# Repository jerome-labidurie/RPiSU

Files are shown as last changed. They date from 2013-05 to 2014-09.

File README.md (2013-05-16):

INSTALL:

* Make your own PCB
* Burn firmware
* Connect wires (take a look in PCB files)
* Press On/Off button to start Raspberry Pi
* Copy RPiSU.sh to users home dir
* Execute 'sudo chmod 766 /home/users home dir/RPiSU.sh'
* Add command '/home/user/RPiSU.sh &' above 'exit 0' in /etc/rc.local
* Reboot

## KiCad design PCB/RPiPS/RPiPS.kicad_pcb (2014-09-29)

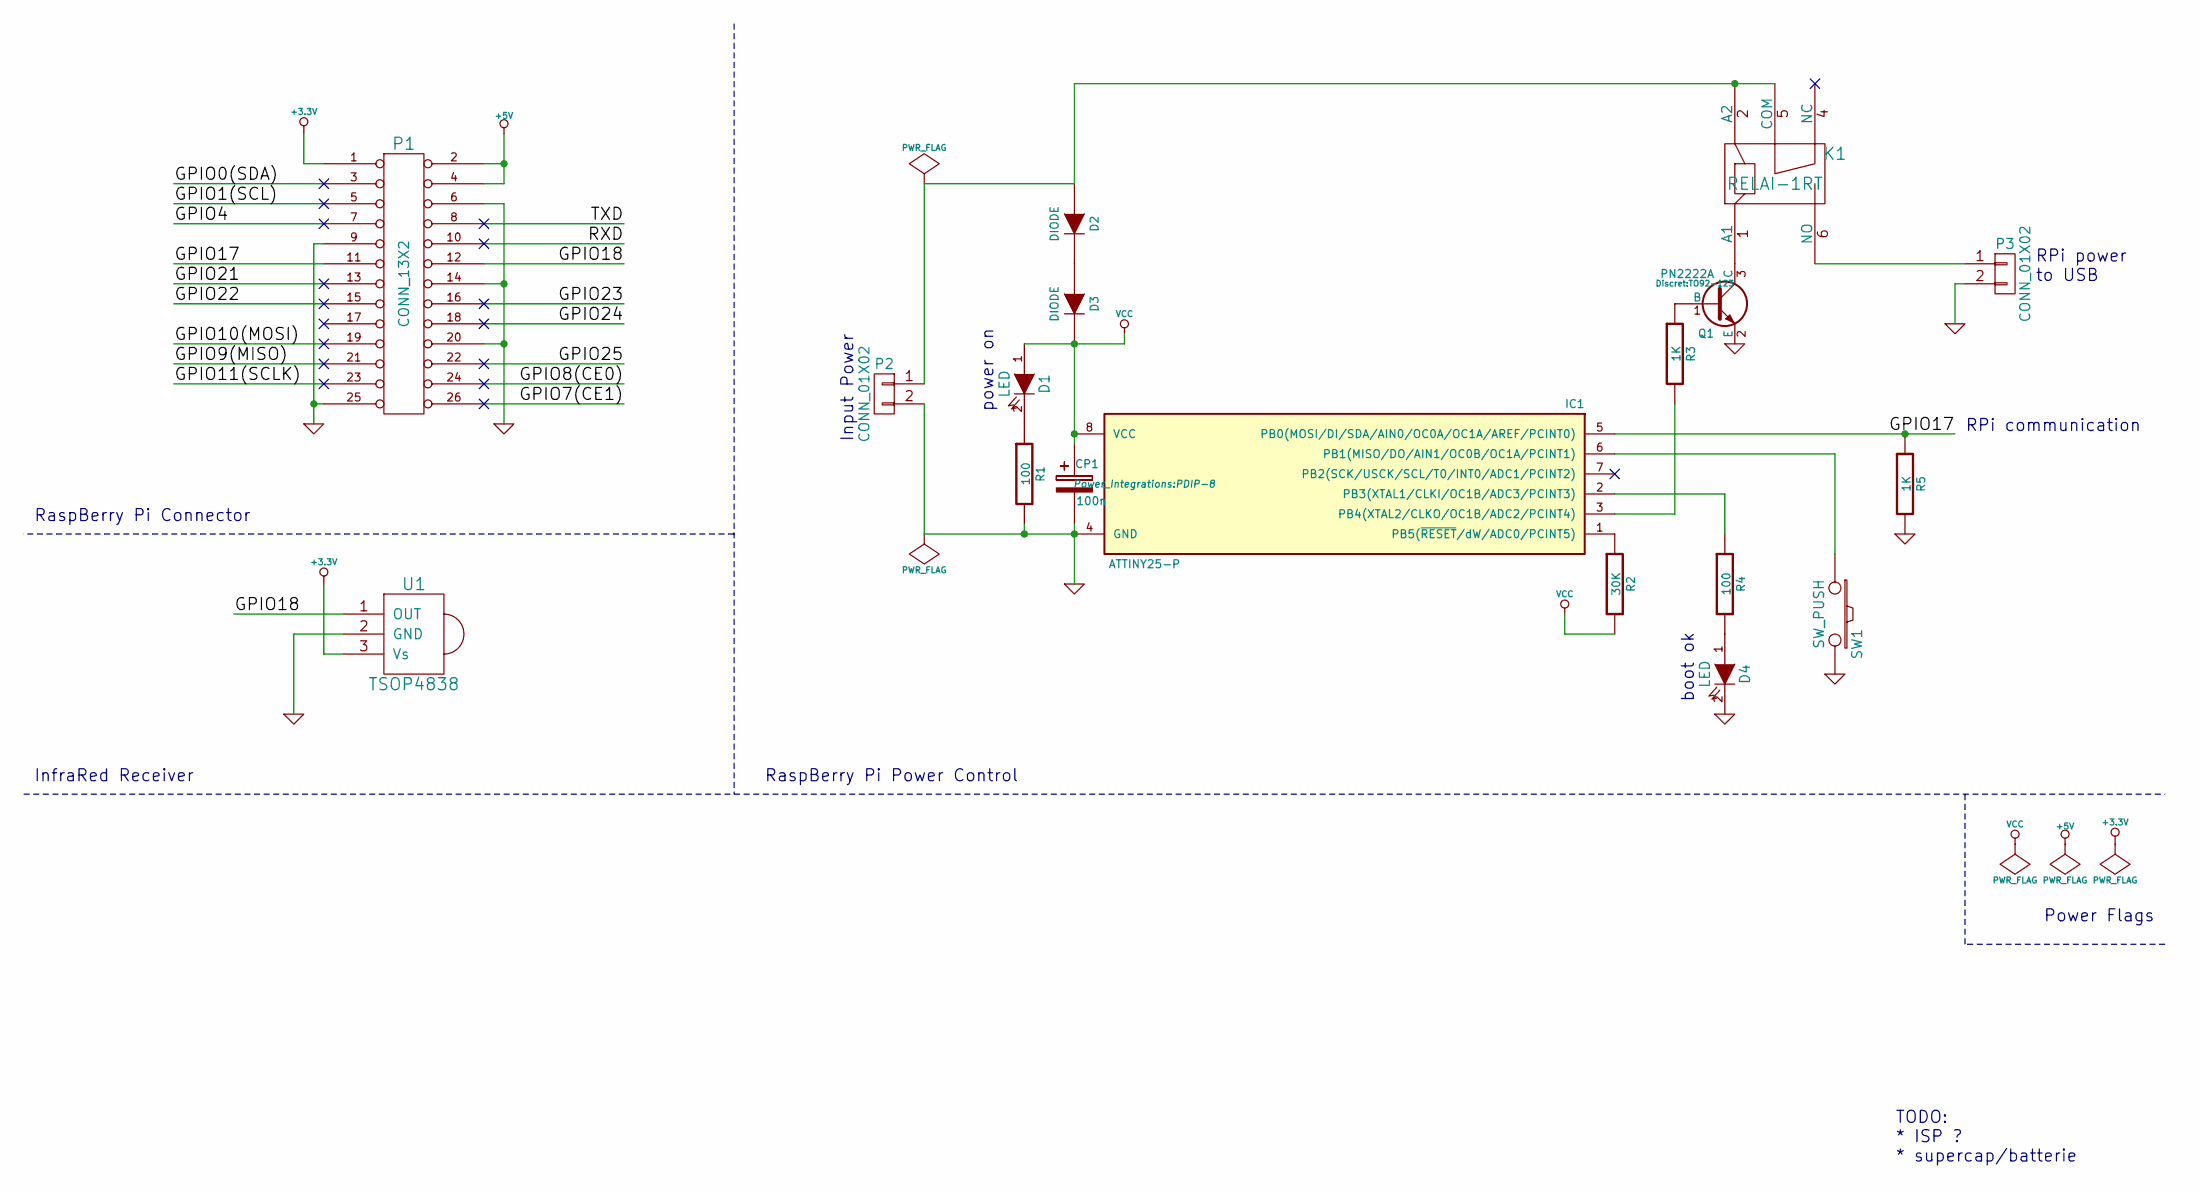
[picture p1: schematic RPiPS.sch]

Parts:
CP1: 100n; Elko_vert_DM5_RM2-5
D1, D4: LED; LED-5MM
D2, D3: DIODE; Diode_DO-35_SOD27_Horizontal_RM10
IC1: ATTINY25-P; PDIP-8
K1: RELAI-1RT; Relay_V23040
P1: CONN_13X2; pin_array_2x13
P2, P3: CONN_01X02; bornier2
Q1: PN2222A; TO92-123
R1, R4: 100; Resistor_Horizontal_RM10mm
R2: 30K; Resistor_Horizontal_RM10mm
R3, R5: 1K; Resistor_Horizontal_RM10mm
SW1: SW_PUSH
U1: TSOP4838

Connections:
+3.3V: P1.1, U1.3 (Vs)
+5V: P1.2, P1.4
/GPIO0(SDA): P1.3
/GPIO1(SCL): P1.5
/GPIO4: P1.7
/GPIO7(CE1): P1.26 (P22)
/GPIO8(CE0): P1.24 (P20)
/GPIO9(MISO): P1.21
/GPIO10(MOSI): P1.19
/GPIO11(SCLK): P1.23
/GPIO17: IC1.5 (PB0(MOSI/DI/SDA/AIN0/OC0A/OC1A/AREF/PCI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), P1.11, R5.1
/GPIO18: P1.12, U1.1 (OUT)
/GPIO21: P1.13
/GPIO22: P1.15
/GPIO23: P1.16
/GPIO24: P1.18
/GPIO25: P1.22
/RXD: P1.10
/TXD: P1.8
GND: CP1.2, D4.2 (K), IC1.4 (GND), P1.6, P1.9, P1.14, P1.20, P1.25 (P24), P2.2, P3.2, Q1.2 (E), R1.2, R5.2, SW1.2, U1.2 (GND)
unnamed: D1.2 (K), R1.1
unnamed: D2.1 (A), K1.2 (A2), K1.5 (COM), P2.1
unnamed: D2.2 (K), D3.1 (A)
unnamed: D4.1 (A), R4.2
unnamed: IC1.1 (PB5(~RESET~/dW/ADC0/PCINT5)), R2.1
unnamed: IC1.2 (PB3(XTAL1/CLKI/OC1B/ADC3/PCINT3)), R4.1
unnamed: IC1.3 (PB4(XTAL2/CLKO/OC1B/ADC2/PCINT4)), R3.2
unnamed: IC1.6 (PB1(MISO/DO/AIN1/OC0B/OC1A/PCINT1)), SW1.1
unnamed: K1.1 (A1), Q1.3 (C)
unnamed: K1.6 (NO), P3.1
unnamed: Q1.1 (B), R3.1
VCC: CP1.1, D1.1 (A), D3.2 (K), IC1.8 (VCC), R2.2

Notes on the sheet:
RPi power to USB
RPi communication
Input Power
TODO: * ISP ? * supercap/batterie
InfraRed Receiver
RaspBerry Pi Power Control
RaspBerry Pi Connector
Power Flags
power on
boot ok

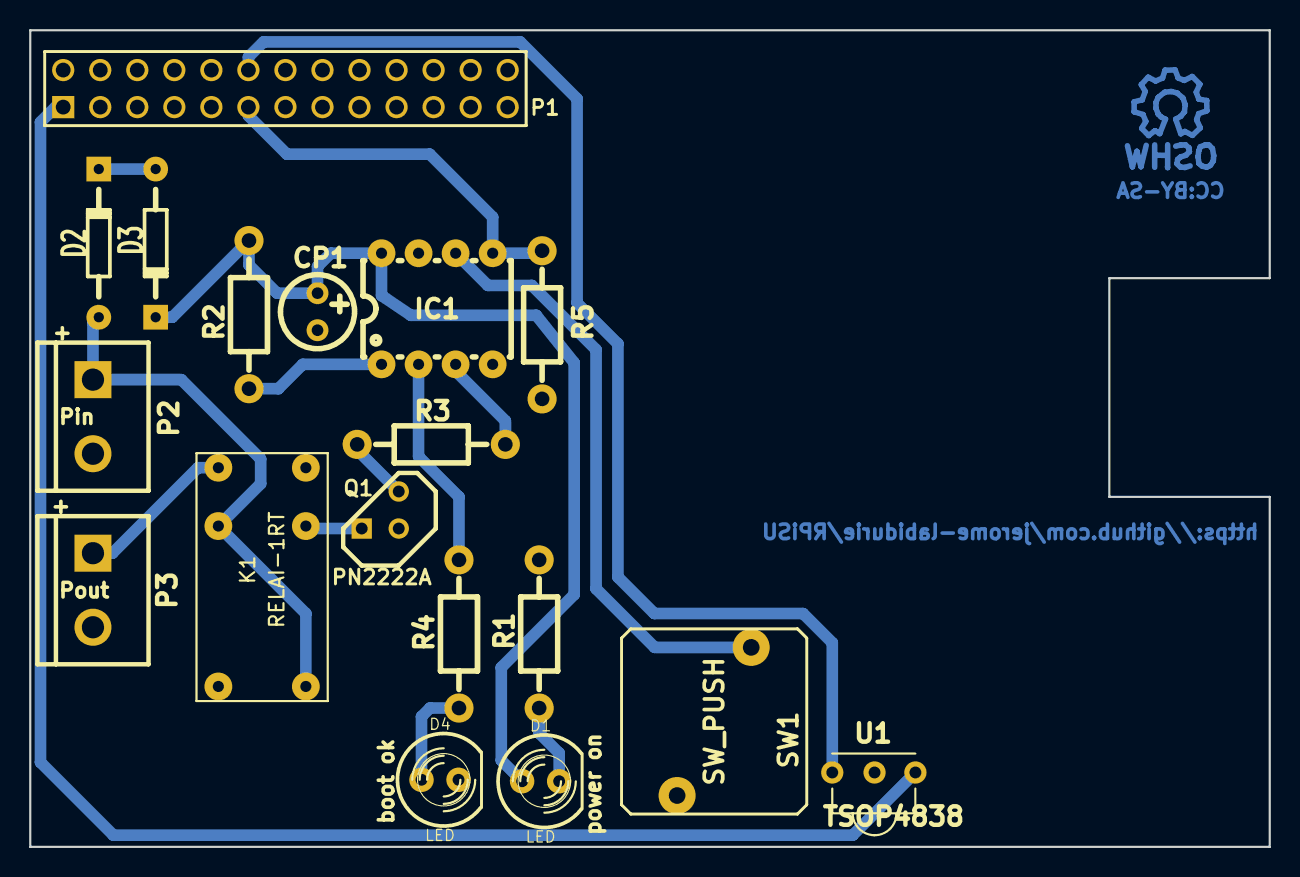
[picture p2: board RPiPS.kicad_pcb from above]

Board: 2 copper layers, 85.0 x 56.0 mm, 19 parts (1 on the bottom side), 17 nets.

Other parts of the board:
SYM: Symbol_OSHW-Logo_CopperTop_07Jul2012; Symbol_OSHW-Logo_CopperTop

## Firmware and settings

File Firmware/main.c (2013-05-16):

#include <avr/io.h>
#ifndef F_CPU
#warning "F_CPU war noch nicht definiert, wird nun mit 1000000 definiert"
#define F_CPU 1000000UL
#endif
#include <util/delay.h>

void sleep(uint16_t ms)
{
    for(; ms > 0; ms--) _delay_ms(1);
}

inline uint8_t debounce(volatile uint8_t *port, uint8_t pin)
{
    if(!(*port & (1<<pin))) // Check low level for button pressed
    {
        sleep(100); // Give user some time to release the button
        if(*port & (1<<pin)) // If button released there is a high level
        {
            sleep(250); // Wait a while for new button check
            return 1;
        }
    }
    return 0;
}

void init(void)
{
    DDRB &= ~((1<<DDB0) | (1<<DDB1) | (1<<DDB2)); // Set pin 1 and 2 to input (1: Power, 2: Reset, 0: Raspberry Pi)
    PORTB |= (1<<PB1); // enable Pullup
    PORTB |= (1<<PB2); // enable Pullup
    DDRB |= (1<<DDB3); // Set pin 3 to output (3: Relais)
}

void powerOn(void)
{
    PORTB |= (1<<PB3); // Set Relais ON
}

void powerOff(void)
{
    PORTB &= ~(1<<PB3); // Set Relais OFF
}

int waitForOn(void)
{
    while(1)
    { // Wait for button pressed
        if(debounce(&PINB, PB1)) return 1;
    }
    return 0;
}

int waitForOffRst(void)
{
    while(1)
    { // Wait for button pressed
        if(debounce(&PINB, PB1)) return 1; // On/Off button pressed
        if(debounce(&PINB, PB2)) { // Reset button pressed
            powerOff();
            return 0;
        }
    }
    return 0;
}

void waitForRPiOn(void)
{
    while(!(PINB & (1<<PINB0)))
    { // Wait for Raspberry Pi
        ;
    }
}

void waitForRPiOff(void)
{
    while(PINB & (1<<PINB0))
    { // Wait for Raspberry Pi
        ;
    }
}

void sendShutdown()
{
    DDRB |= (1<<DDB0); // Set pin 0 to output (0: Raspberry Pi)
    PORTB |= (1<<PB0); // HIGH
    sleep(1000); // Give RPi a 1 second HIGH pulse
    PORTB &= ~(1<<PB0); // LOW
    DDRB &= ~(1<<DDB0); // Set pin 0 to input (0: Raspberry Pi)
    sleep(2000); // Wait for RPi
}

int main(void)
{
    while(1)
    {
        init(); // Init Ports
        waitForOn(); // Wait until user pressed On/Off button
        powerOn(); // RPi power on
        waitForRPiOn(); // Wait for RPi ready signal
        if(!waitForOffRst()) continue; // If button On/Off pressed, shutdown. If button Reset pressed, reset.
        // This code only execute if user pressed On/Off button.
        sendShutdown(); // Send shutdown signal
        waitForRPiOff(); // Wait until RPi shutting down
        sleep(5000); // Wait for safe shutdown
        powerOff(); // RPi power off
    }
    return 0;
}

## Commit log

2014-01-05 New scheme using Kicad
    [RPiPS.sch]
2014-09-27 Move to RPi Expansion board template
    [RPiPS.dsn, RPiPS.kicad_pcb, RPiPS.sch]
2014-09-28 add IR receiver pcb routing fabrication files
    [RPiPS.kicad_pcb, RPiPS.sch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]
2014-09-28 OSHW logo relay footprint
    [RPiPS.kicad_pcb, RPiPS.sch]
2014-09-29 remove gnd plane over Pi connectors reverse P2 (1 is +) minor Silk adjustment
    [RPiPS.kicad_pcb, RPiPS.sch]
